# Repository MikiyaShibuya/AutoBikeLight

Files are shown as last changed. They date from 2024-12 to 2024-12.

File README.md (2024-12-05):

# AutoBikeLED

## コンセプト
- 既製品から取り出した回路を利用
- ヘッドライト・リアライト・サイコン照明を一つのシステムで駆動
  - リアライトは走行を検知して点灯
  - ヘッドライト・サイコン照明は走行中かつ暗いときに自動で点灯

## 回路図

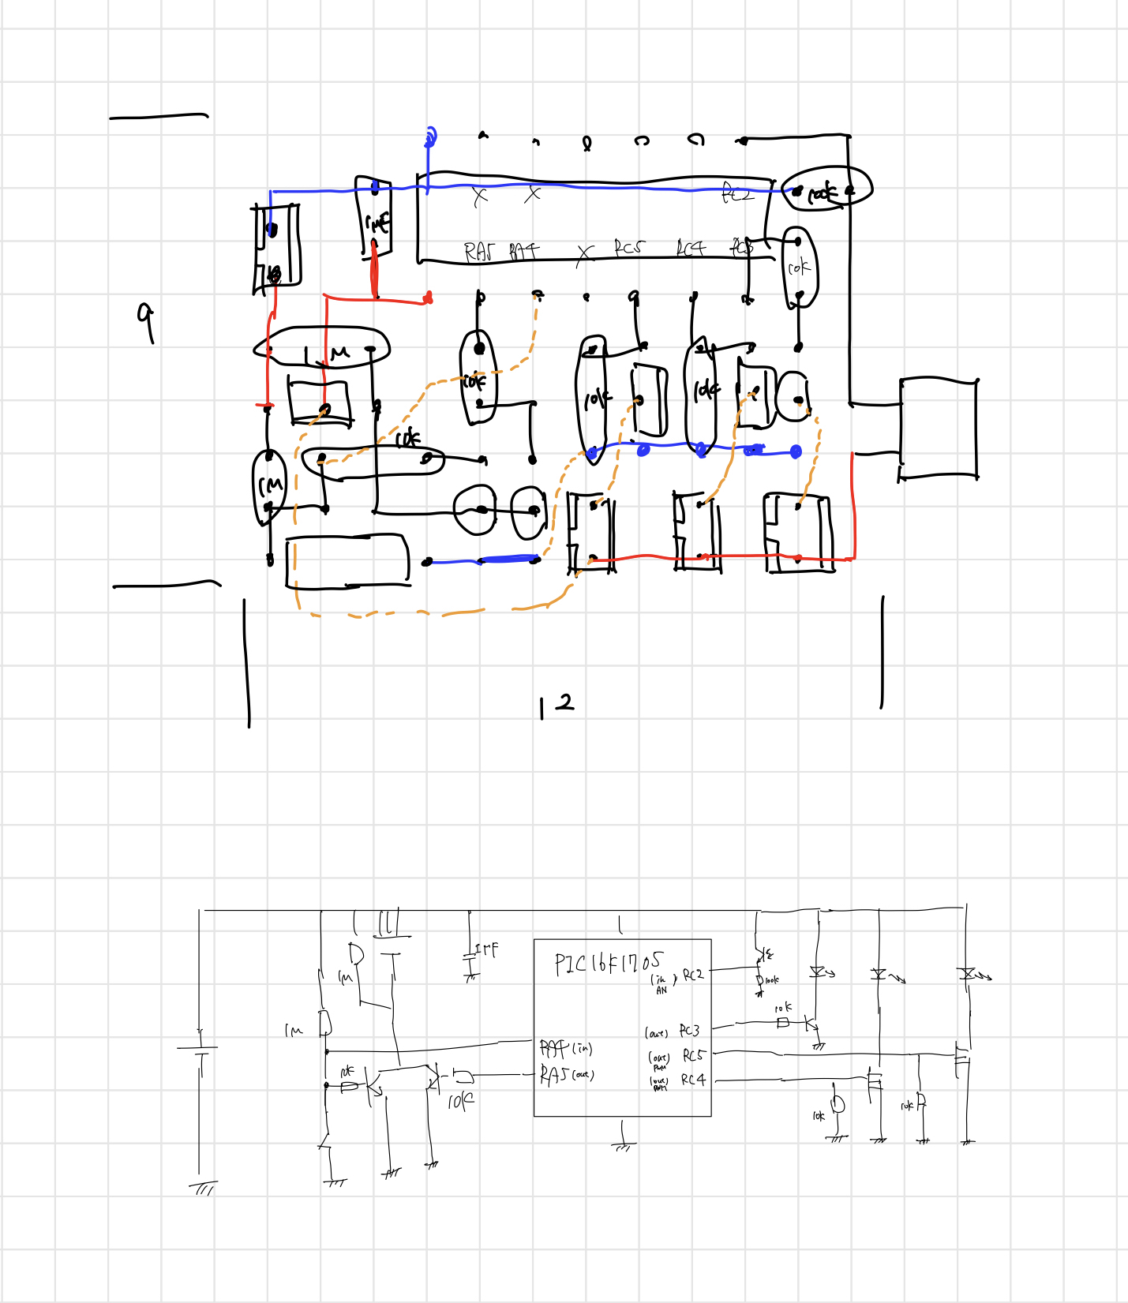
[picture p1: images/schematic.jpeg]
schematck


## 計測値

## 昼間消費電力
0.265W (0.053A @ 5V)
- ヘッド: 3/124, テール：4/124、メーター：0/124

# 夜間消費電力
1.565W (0.313A @ 5V)
- ヘッド：24/124, テール：4/124, メーター: 3/124

### ヘッドライト
- 0.185A (0.925W) @ 5V 15/124
- 0.065A (0.325W) @ 5V 5/124
- 0.039A (0.195W) @ 5V 3/124
- 0.071A (0.2627W) @ 3.7V 15/124

- 1.010A (5.05W) @ 5V 80/124
- 0.348A (1.74W) @ 5V 27/124
- 0.305A (1.525W) @ 5V 24/124
- 0.387A (1.4319W) @ 3.7V 80/124

### メーター
- 0.007A (0.035W) @ 5V 15/124
- 0.007A (0.035W) @ 5V 5/124
- 0.007A (0.035W) @ 5V 3/124
- 0.003A (0.0111W) @ 3.7V 15/124

### テールランプ
- 0.053A (0.265W) @ 5V 10/124
- 0.028A (0.14W) @ 5V 5/124
- 0.026A (0.13W) @ 5V 4/124
- 0.030A (0.111W) @ 3.7 10/124

- 0.202A (1.01W) @ 5V 40/124
- 0.089A (0.445W) @ 5V 15/124
- 0.116A (0.4292W) @ 3.7V 40/124

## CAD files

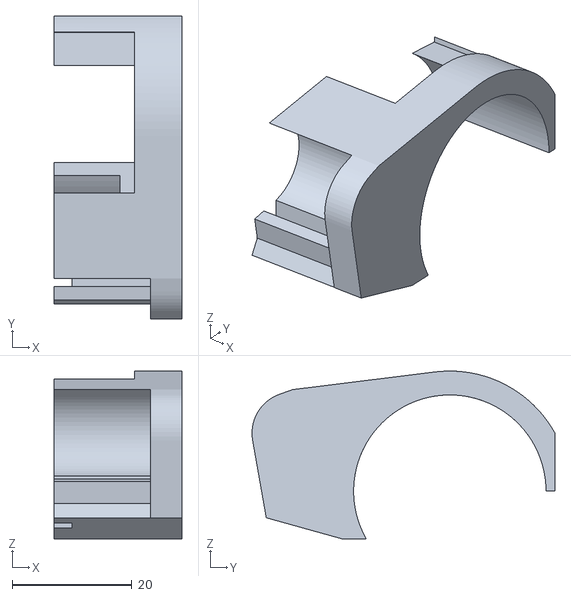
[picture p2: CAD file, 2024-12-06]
3D_models/headlight_holder_L_v2.stl
21.3 x 50.7 x 28.1

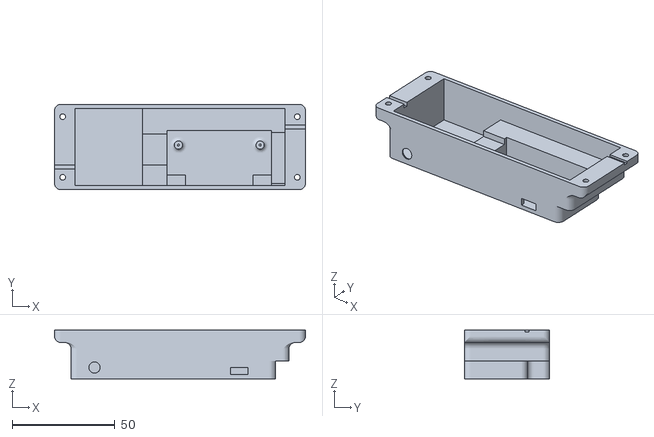
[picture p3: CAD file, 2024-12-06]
3D_models/circuit_case.stl
122.2 x 41.5 x 23.7

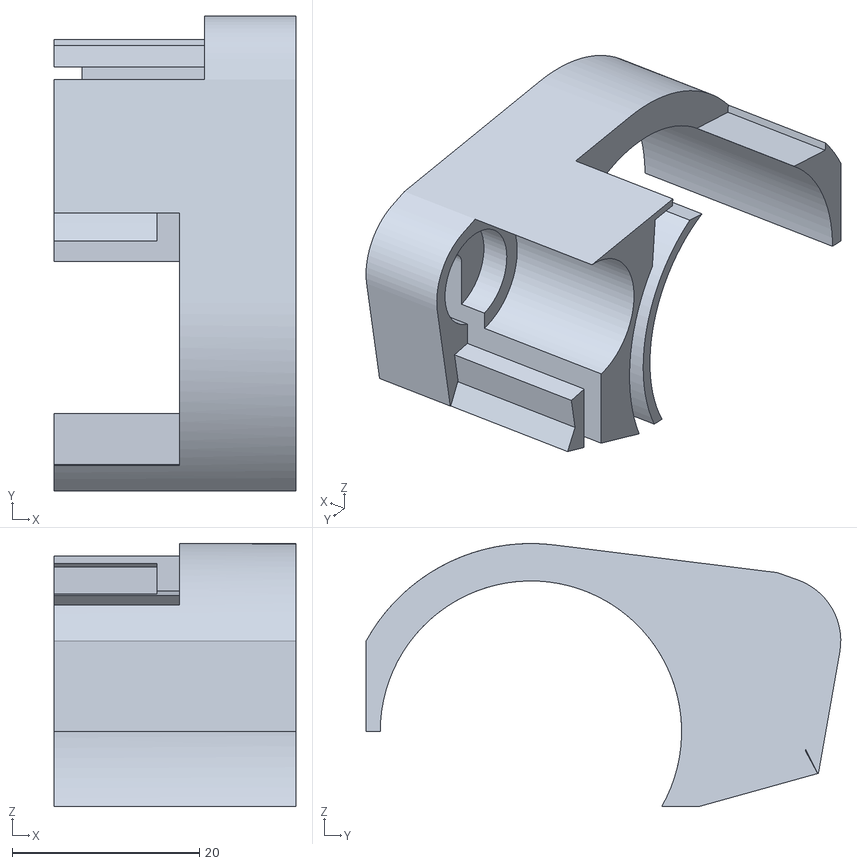
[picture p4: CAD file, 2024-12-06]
3D_models/headlight_holder_R.stl
25.8 x 50.7 x 28.1

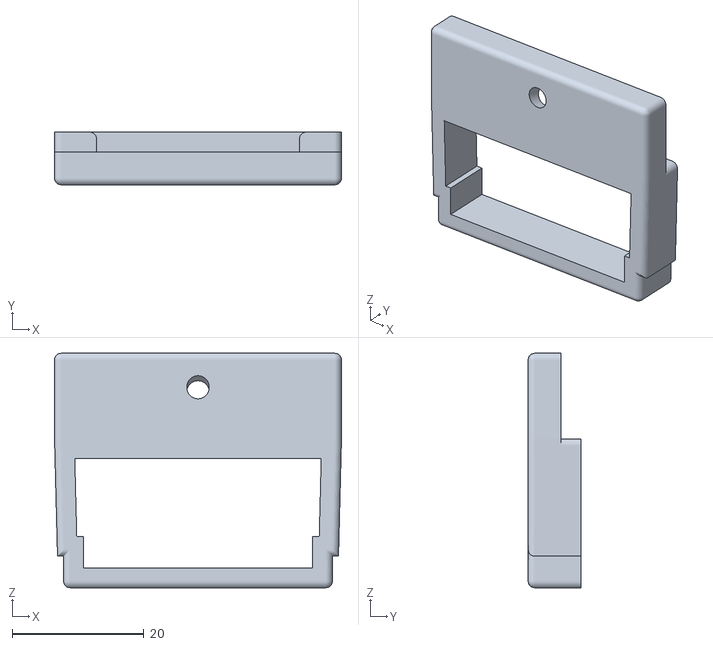
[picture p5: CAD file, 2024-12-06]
3D_models/meter_lamp_holder.stl
43.6 x 8.00 x 35.6

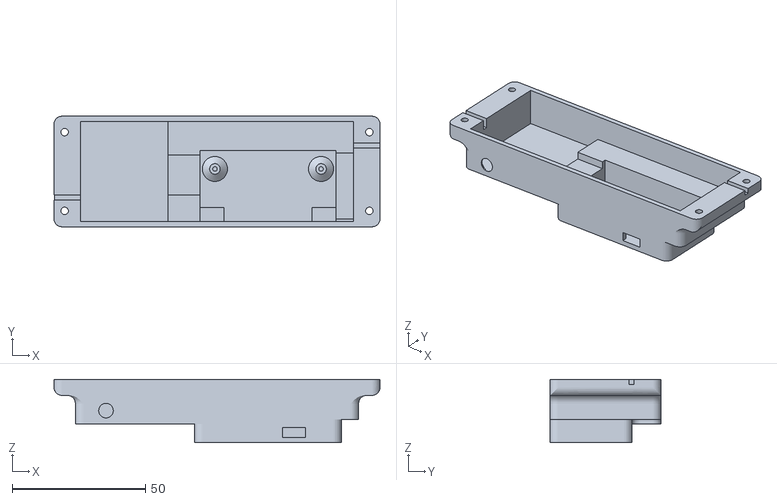
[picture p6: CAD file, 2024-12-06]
3D_models/circuit_case_v2.stl
122.2 x 41.5 x 23.7

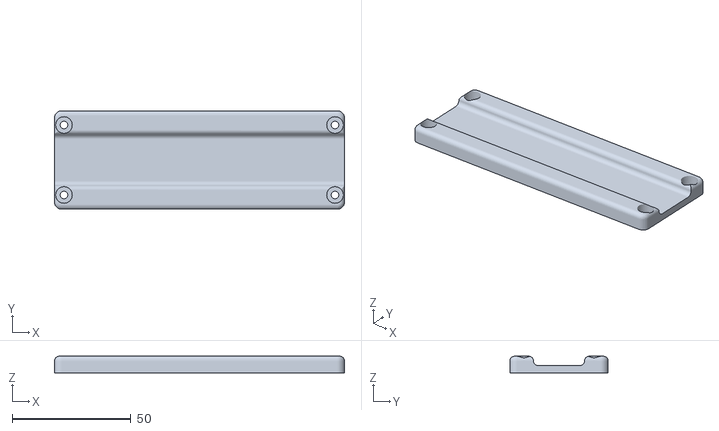
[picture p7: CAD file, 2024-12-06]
3D_models/circuit_cover.stl
122.2 x 41.5 x 7.00

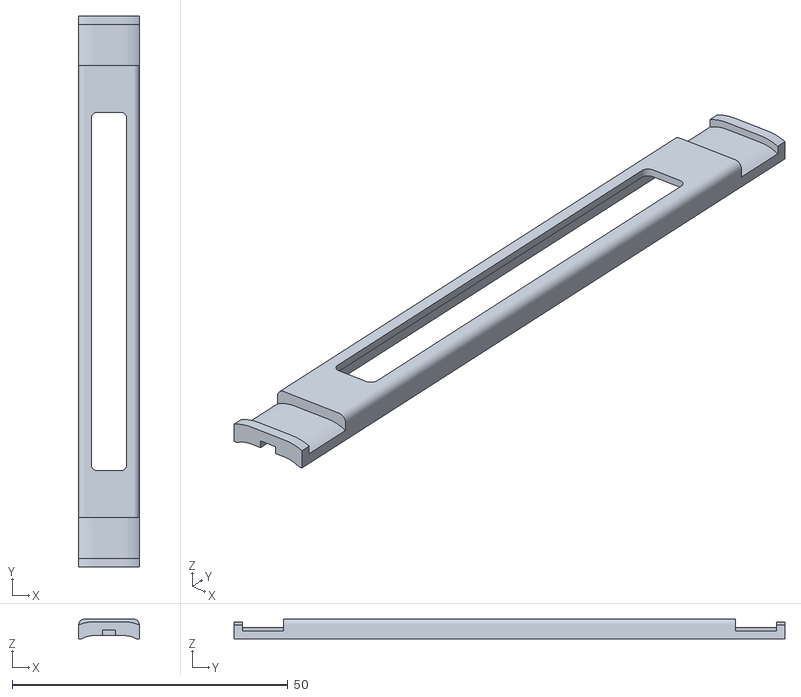
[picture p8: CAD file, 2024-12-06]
3D_models/tail_lamp_cover.stl
11.0 x 100.0 x 3.61

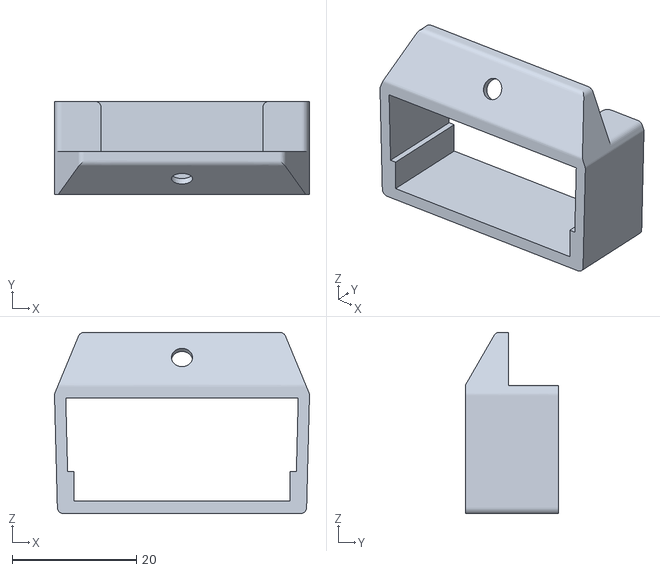
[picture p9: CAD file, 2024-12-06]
3D_models/meter_lamp_holder_v4.stl
41.0 x 15.0 x 29.2

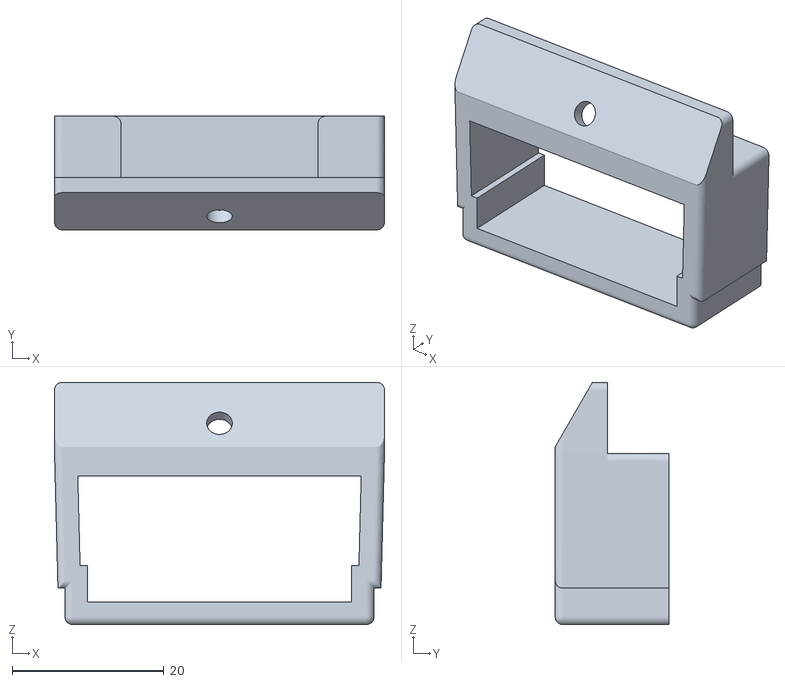
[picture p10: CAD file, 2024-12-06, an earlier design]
3D_models/meter_lamp_holder_v3.stl
43.6 x 15.0 x 32.0

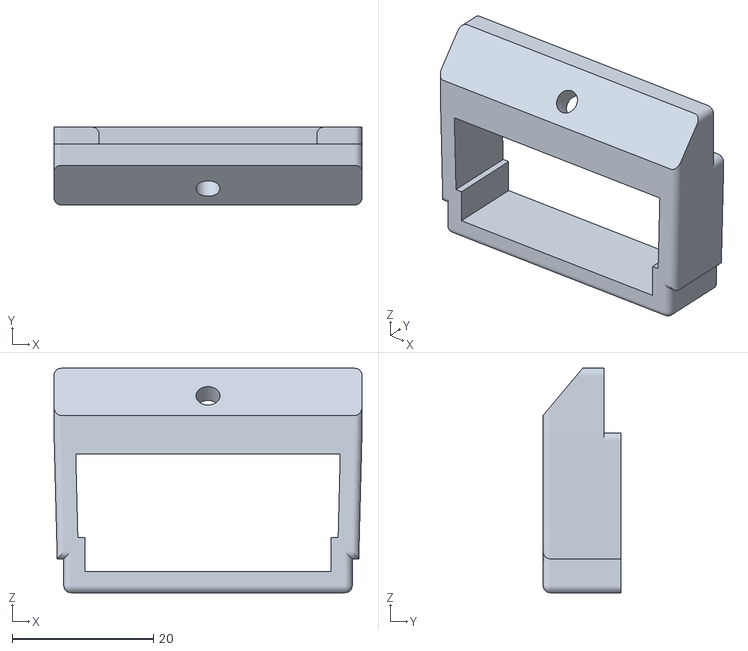
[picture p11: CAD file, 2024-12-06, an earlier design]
3D_models/meter_lamp_holder_v2.stl
43.6 x 11.0 x 31.7

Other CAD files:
3D_models/headlight_holder_R_v2.stl
3D_models/headlight_holder_L.stl

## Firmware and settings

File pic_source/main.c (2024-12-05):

/*
 * File:     main.c
 * Author: shibuya
 *
 * Created on August 29, 2022, 12:53 PM
 */

#include <xc.h>

// CONFIG1
#pragma config FOSC = INTOSC     // Use internal clock
#pragma config WDTE = OFF        // Disable watch dog timer
#pragma config PWRTE = ON        // Enable power-up timer
#pragma config MCLRE = OFF       // Use MCLR pin as RA3
#pragma config CP = OFF          // Don't protect program memory
#pragma config BOREN = ON        // Enable brown out reset
#pragma config CLKOUTEN = OFF    // Don't use clock out, use as RA4
#pragma config IESO = OFF        // Disable 2-stage clocks start up
#pragma config FCMEN = OFF       // Don't monitor clock

// CONFIG2
#pragma config WRT = OFF         // Don't protect flash memeory
#pragma config PPS1WAY = OFF     // Allow to try to unlock PPSLOCK anytime
#pragma config ZCDDIS = ON       // Disable zero cross detection
#pragma config PLLEN = OFF       // Disable ×4PLL
#pragma config STVREN = ON       // Enable stack overflow reset
#pragma config BORV = HI         // Set brown out trigger voltage as high
#pragma config LPBOR = OFF       // Disable low power brown out reset
#pragma config LVP = OFF         // Disable low voltage programming

#define _XTAL_FREQ 8000000

#define PWR_EN RA5

typedef unsigned char uint8_t;
// typedef unsigned int uint16_t; You can use this type
typedef unsigned long uint32_t;

// Count of 1 day
const static uint32_t COUNT_1DAY = 86400 * 1024;
// Initial value of countdown timer to measure 1/1024 sec
const static int TMR_CNT_H = (65536 - 235) >> 8;
const static int TMR_CNT_L = (65536 - 235) & 0xff;

// Time to keep powered when not moving
const static uint32_t STATIONAL_COUNT = 3L * 60 * 1024; // 3 min

// Duty ratio is [DUTY VALUE] / 124
const static char METER_LAMP_DUTY = 3;
const static char HEADLIGHT_DUTY = 24;
const static char HEADLIGHT_DAY_DUTY = 3;
const static char TAIL_LAMP_DIM_DUTY = 4;
const static char TAIL_LAMP_FLASH_DUTY = 15;
const static int BRIGHT_DURATION = 60;

// Brightness thresholds
const static int AMB_BRIGHT_THR_LOW = 500;
const static int AMB_BRIGHT_THR_HIGH = 800;

// Count 1024th of 1 sec since vibration sensor stopped, max 86400 * 1024 = 1day
volatile static uint32_t count;
// Millisecond count (1/1024 sec in precisely) since when chip was powered
volatile static uint16_t millis;

// Get analog voltage as a floating point value in 0 to 1023
int read_adc(int channel) {

    if (channel == 0) {
        ADCON0 = 0b00001101; // Use AN3(RA4)
    }
    else {
        ADCON0 = 0b00011001; // Use AN6(RC2)
    }

    // Start A/D conversion
    ADCON0 = ADCON0 | 0b00000010;

    // Wait for A/D conversion process
    while(1) {
        uint8_t not_done = ADCON0 & 0b00000010;
        if (not_done == 0) {
            break;
        }
    }

    return (ADRESH * (int)0x100 + ADRESL);
}

// Reset timer1 count
void restart_counter() {
    GIE = 0;
    count = 0;
    TMR1H = TMR_CNT_H;
    TMR1L = TMR_CNT_L;
    TMR1IF = 0;
    GIE = 1;
}

// Interrupt function
void __interrupt() isr(){
    GIE = 0;
    if (TMR1IF == 1) {
        if (count < COUNT_1DAY) {
            count ++;
        }
        millis = (millis + 1) & 0x03ff;
        TMR1H = TMR_CNT_H;
        TMR1L = TMR_CNT_L;
        TMR1IF = 0;
    }
    GIE = 1;
}

void main() {

    OSCCON = 0b01110010; // [6:2]=1110 -> 8MHz
    ANSELA = 0b00000000; // Don't use Analog-A
    ANSELC = 0b00000000; // Don't use Analog-C
    TRISA = 0b00010000; // Only RA4 is input
    TRISC = 0b00000100; // Only RC2 is input
    PORTA = 0b00000000; // Initialize A port
    PORTC = 0b00000000; // Initialize C port

    PWR_EN = 1; // Enable power ASAP

    RC5PPS = 0b00001110; // Use RC5 port as PWM3OUT
    PWM3CON = 0b10000000; // Enable PWM3, active high

    RC4PPS = 0b00001111; // Use RC4 port as PWM4OUT
    PWM4CON = 0b10000000; // Enable PWM4, active high

    CCPTMRS = 0b00000000; // All PWM and CCP modules uses TMR2

    ADCON0 = 0b00011001;
    ADCON1 = 0b10110000; // Use internal clock, reference for Vdd and Vss
    ADCON2 = 0b00000000; // Don't use auto-conversion trigger

    T1CON = 0b00110101; // 1/4 clock source, 1:8 prescaler, enable TMR1
    TMR1H = (65536 - 10) >> 8;
    TMR1L = (65536 - 10) & 0xff;
    count = 0;
    millis = 0;
    TMR1IE = 1;
    TMR1IF = 0;
    PEIE = 1;
    GIE = 1;

    PR2 = 124; // 1kHz
    PWM3DCH = 0;
    PWM3DCL = 0;
    PWM4DCH = 0;
    PWM4DCL = 0;

    T2CON = 0b00000110; // Turn on TMR2 with x16 pre-scaler

    char vib_sns_prev = read_adc(0) > 50 ? 1 : 0; // Read from RA4
    int adc_value_itg = 0;

    // Produce third PWM in main loop, this is used for meter lamp;
    int pwm_count = 0;
    int pwm_duty = 1;
    int pwm_period = 8;
    
    char is_amb_dark = 1;

    while(1) {
        // Check ambient brightness as frequent as PWM
        if (pwm_count == 0) {
            // Read analog value from RC2 (0 - 1023)
            int adc_value_read = read_adc(1);
            // Filter
            adc_value_itg = adc_value_itg - (adc_value_itg >> 3) + (adc_value_read >> 3);
        }

        if (is_amb_dark == 1 && adc_value_itg > AMB_BRIGHT_THR_HIGH) {
            is_amb_dark = 0;
        }
        else if (is_amb_dark == 0 && adc_value_itg <= AMB_BRIGHT_THR_LOW) {
            is_amb_dark = 1;
        }

        // Check vibration every 1/8 sec
        if (count % 128 == 0) {
            char vib_sns = read_adc(0) > 50 ? 1 : 0;
            // Reset counter
            if (vib_sns_prev != vib_sns) {
                vib_sns_prev = vib_sns;
                restart_counter();
            }
        }

        // Turn off all lights when the bike keeps be stational for a while
        if (count > STATIONAL_COUNT) {
            PWR_EN = 0;
            PWM3DCH = 0;
            PWM4DCH = 0;
        }
        else {
            // Keep turn on main power switch
            PWR_EN = 1;
            
            // Turn on headlight when the ambient light is dark
            if (is_amb_dark) {
                PWM3DCH = HEADLIGHT_DUTY;
            }
            else{
                PWM3DCH = HEADLIGHT_DAY_DUTY;
            }

            // Flash tail lamp
            if (millis < BRIGHT_DURATION) {
                PWM4DCH = TAIL_LAMP_FLASH_DUTY;
            }
            else if (100 <= millis && millis < 100 + BRIGHT_DURATION) {
                PWM4DCH = TAIL_LAMP_FLASH_DUTY;
            }
            else {
                PWM4DCH = TAIL_LAMP_DIM_DUTY;
            }
        }

        if (pwm_count < pwm_duty && is_amb_dark) {
                RC3 = 1;
        }
        else {
                RC3 = 0;
        }
        pwm_count = (pwm_count + 1) % pwm_period;
    }
    return;
}

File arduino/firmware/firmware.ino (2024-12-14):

#include <Arduino.h>

// ====  Pin configuration ====
#define PIN_VIB_SNS 0
#define PIN_AMB_SNS 1
#define PIN_PW_CTL 4
#define PIN_MT_LED 5
#define PIN_HL_LED 6
#define PIN_TL_LED 7

// ==== Parameters ====

// Timeout
#define MAX_CNT 180 // timeout in second

// Sensor
#define VIB_THRESHOLD 100 // 0-1023, lower is more sensitive
// 0-1023, lower is darker
#define AMB_THRESHOLD_NIGHT 700 // It's night if ambient light is below this
#define AMB_THRESHOLD_DAY 850   // It's day if ambient light is above this

// Flash control
#define BLINK_PERIOD_1 60  // FLASH
#define BLINK_PERIOD_2 40  // DIM
#define BLINK_PERIOD_3 60  // FLASH
#define BLINK_PERIOD_4 840 // DIM

// Brightness (0-255)
// Meter brightness is constant
#define METER_BRIGHTNESS 15
// Headlight brightness is different for day and night
#define HEADLIGHT_DAY_BRIGHTNESS 4
#define HEADLIGHT_NIGHT_BRIGHTNESS 30
// Taillight brightness is not changed in day or night but it blinks
#define TAILLIGHT_BASE_BRIGHTNESS 5
#define TAILLIGHT_BRIGHTNESS 24

bool is_dark = false;

// This is working on 20MHz
// 22.7us per adc read
// (5 * 1000 * 100 times adc read took 11.35s)

void wait_ms(int ms, int *cnt, bool drive_light) {

  ms = ms * 0.94; // Cancel out adc sampling delay

  for (int i = 0; i < ms; i++) {
    // 51.7us per loop
    {
      if (drive_light) {
        const int amb = analogRead(PIN_AMB_SNS); // 0-1023
        if (is_dark) {
          is_dark = amb < AMB_THRESHOLD_DAY;
        } else {
          is_dark = amb < AMB_THRESHOLD_NIGHT;
        }
        if (is_dark) {
          analogWrite(PIN_HL_LED, HEADLIGHT_NIGHT_BRIGHTNESS);
        } else {
          analogWrite(PIN_HL_LED, HEADLIGHT_DAY_BRIGHTNESS);
        }
      }

      const int val = analogRead(PIN_VIB_SNS); // 0-1023

      if (val > VIB_THRESHOLD) {
        *cnt = 0;
      }
    }
    delay(1);
  }
}

void setup() {
  pinMode(PIN_VIB_SNS, INPUT);
  pinMode(PIN_AMB_SNS, INPUT);
  pinMode(PIN_PW_CTL, OUTPUT);
  pinMode(PIN_MT_LED, OUTPUT);
  pinMode(PIN_HL_LED, OUTPUT);
  pinMode(PIN_TL_LED, OUTPUT);

  digitalWrite(PIN_PW_CTL, HIGH);

  int cnt = 0;

  analogWrite(PIN_HL_LED, HEADLIGHT_NIGHT_BRIGHTNESS);
  delay(60);
  analogWrite(PIN_HL_LED, HEADLIGHT_DAY_BRIGHTNESS);
  delay(40);
  analogWrite(PIN_HL_LED, HEADLIGHT_NIGHT_BRIGHTNESS);
  delay(60);
  analogWrite(PIN_HL_LED, HEADLIGHT_DAY_BRIGHTNESS);
  delay(200);

  while (true) {
    // Setup meter light
    analogWrite(PIN_MT_LED, METER_BRIGHTNESS);

    // Blink tail light
    analogWrite(PIN_TL_LED, TAILLIGHT_BRIGHTNESS);
    wait_ms(BLINK_PERIOD_1, &cnt, true);
    analogWrite(PIN_TL_LED, TAILLIGHT_BASE_BRIGHTNESS);
    wait_ms(BLINK_PERIOD_2, &cnt, true);
    analogWrite(PIN_TL_LED, TAILLIGHT_BRIGHTNESS);
    wait_ms(BLINK_PERIOD_3, &cnt, true);
    analogWrite(PIN_TL_LED, TAILLIGHT_BASE_BRIGHTNESS);
    wait_ms(BLINK_PERIOD_4, &cnt, true);

    // Check timeout
    cnt++;
    if (cnt >= MAX_CNT) {
      analogWrite(PIN_MT_LED, 0);
      analogWrite(PIN_HL_LED, 0);
      analogWrite(PIN_TL_LED, 0);

      // Wair for vibration
      while (true) {
        digitalWrite(PIN_PW_CTL, LOW);

        wait_ms(100, &cnt, false);
        if (cnt == 0) {
          break;
        }
      }
    }
  }
}

void loop() {}

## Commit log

2024-12-05 Update schematic and firmware as v0.2
2024-12-05 Update duty for 5V power source
2024-12-06 Add 3d models
    [circuit_case.stl, circuit_case_v2.stl, circuit_cover.stl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]
2024-12-06 Add new arduino source with LED driver and power control on ATtiny404
2024-12-06 Implement day/night switching using ambient light sensor and optimize program
